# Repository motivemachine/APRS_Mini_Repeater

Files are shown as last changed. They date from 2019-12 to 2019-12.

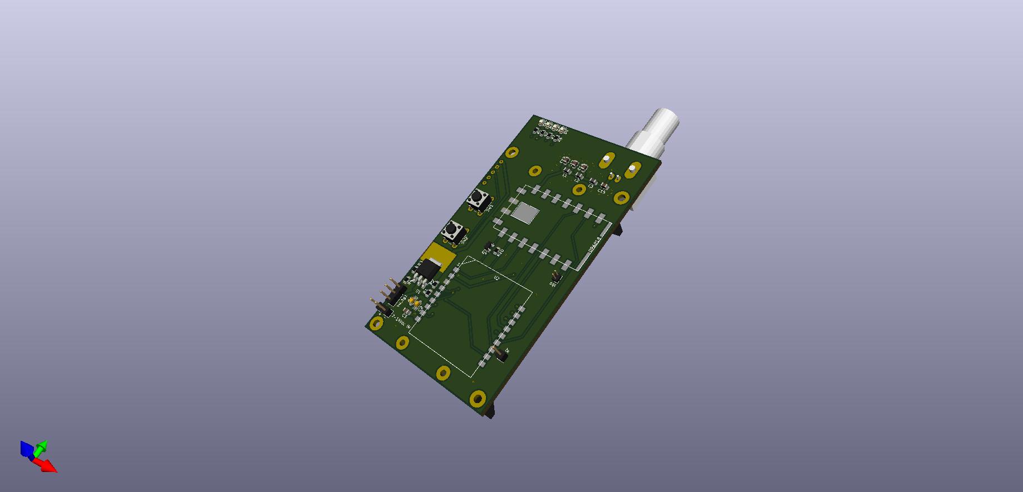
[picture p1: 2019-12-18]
APRS_MicroNode.jpg

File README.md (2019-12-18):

### Project goal
The goal of this in-progress project is to create a simple APRS position reporter and repeater. This will serve as a stepping stone toward my full APRS text-message radio, while providing a useful purpose later as an easy to deploy repeater for better coverage between groups of hikers, bikers, or road-trippers. It will be able to use smart-beaconing to know when to update it's position, and if repeater mode is turned on, repeat any packets heard that are not addressed to it.

This PCB uses the nano-modem board I developed here: [APRS Nanomodem]https://gitlab.com/motivemachine/aprs-nanomodem
Which is based on the Arduino TNC circuit and library developed by Mark Qvist here: [unsigned.io](https://unsigned.io/micromodem/)

### Project status
PCB is complete and undergoing testing. Board is designed in Kicad 5.1, gerbers will be available soon. 

 Writing the code has just started. I'll get the smart beaconing working first, then start in on the repeater functions and [hopefully] get it to conform with the APRS repeater WIDEn-N standard:
[APRS 101](http://www.aprs.org/doc/APRS101.PDF)

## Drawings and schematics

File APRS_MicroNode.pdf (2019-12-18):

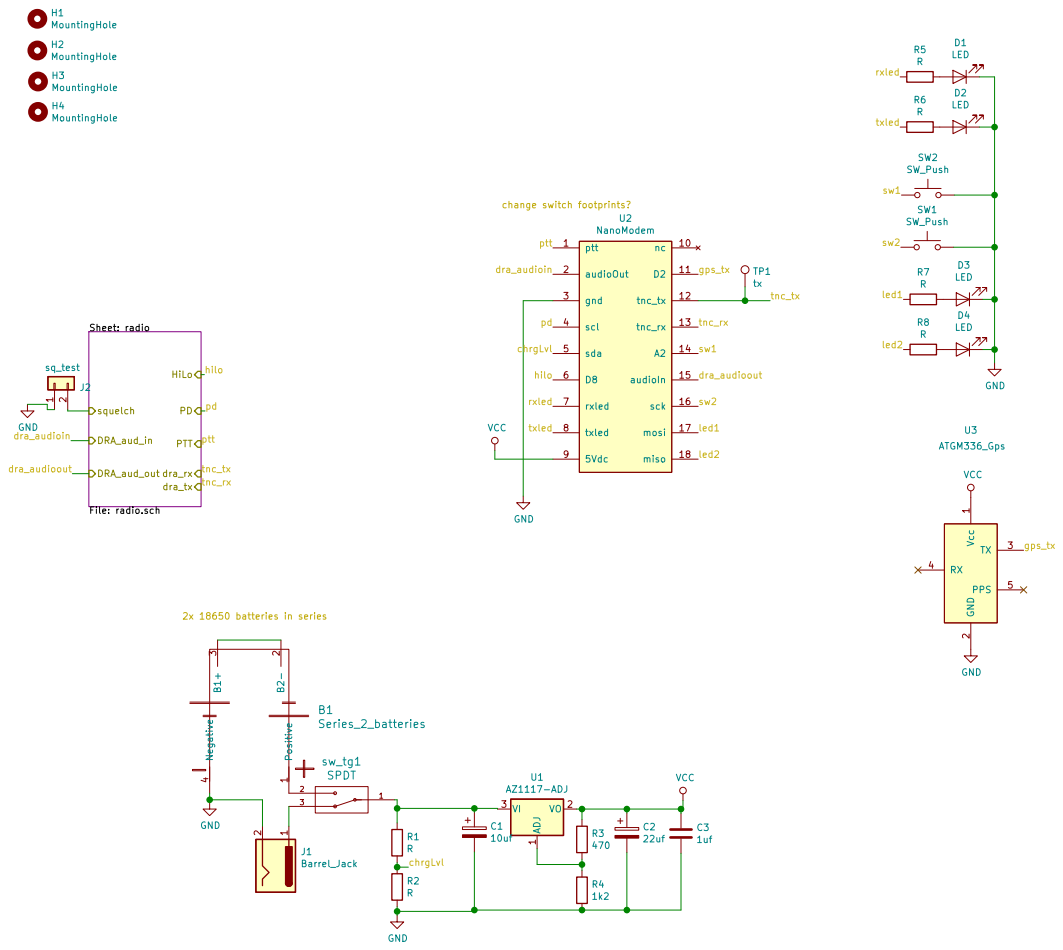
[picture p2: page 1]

2 TX 3 RX 4 PPS 5 U3 ATGM336_Gps SW2 SW_Push SW1 SW_Push GND

4 B1Series_2_batteries ADJ 1 VO 2 VI 3 U1 AZ1117-ADJ C1

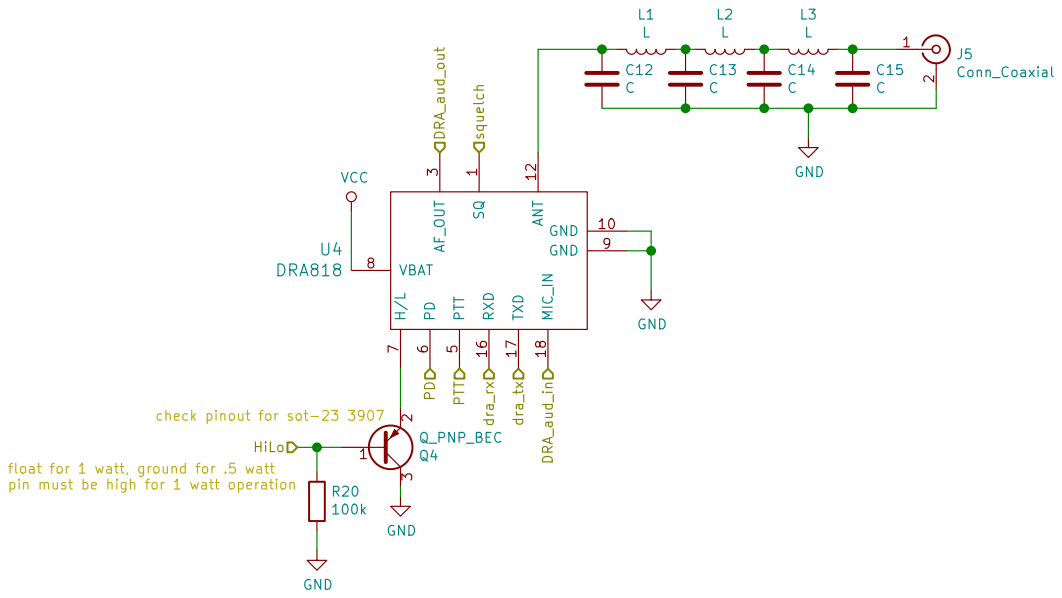
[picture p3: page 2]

1 GND ANT 10 12 RXD 16 TXD 17 MIC_IN 18 AF_OUT

check pinout for sot-23 3907

float for 1 watt, ground for .5 watt
pin must be high for 1 watt operation

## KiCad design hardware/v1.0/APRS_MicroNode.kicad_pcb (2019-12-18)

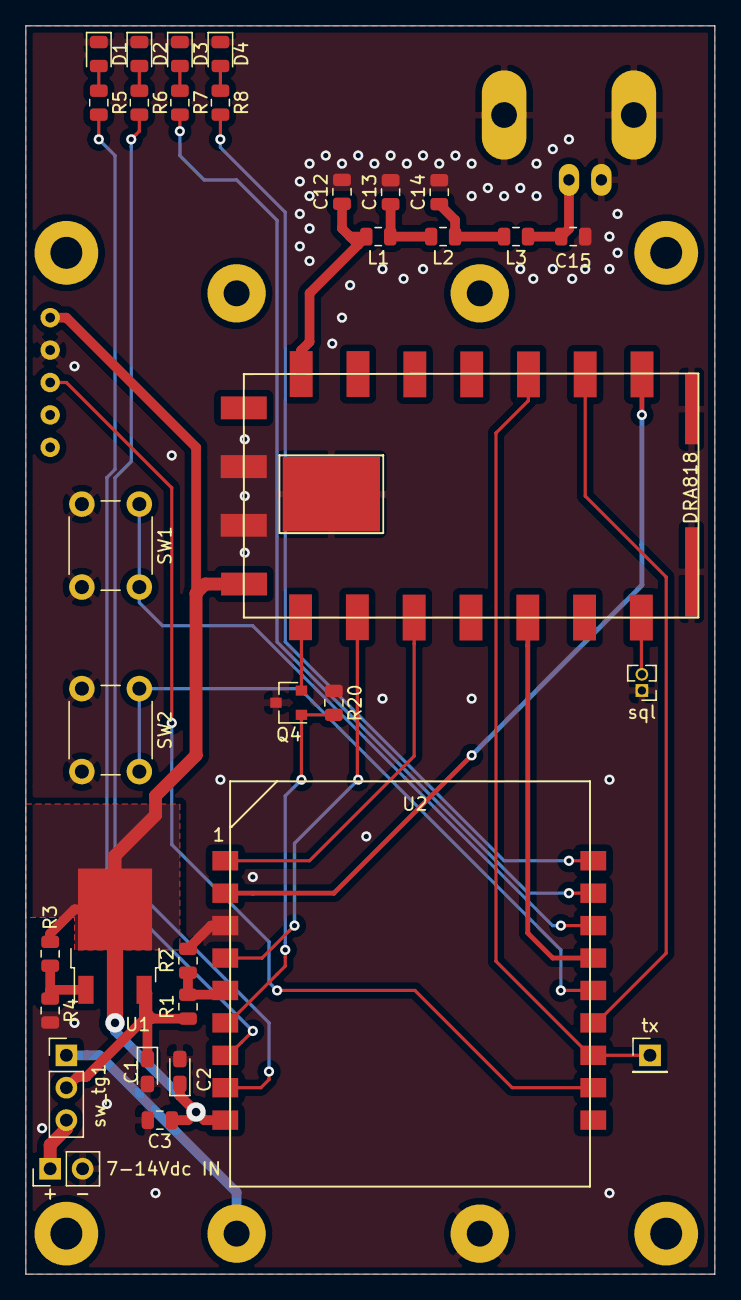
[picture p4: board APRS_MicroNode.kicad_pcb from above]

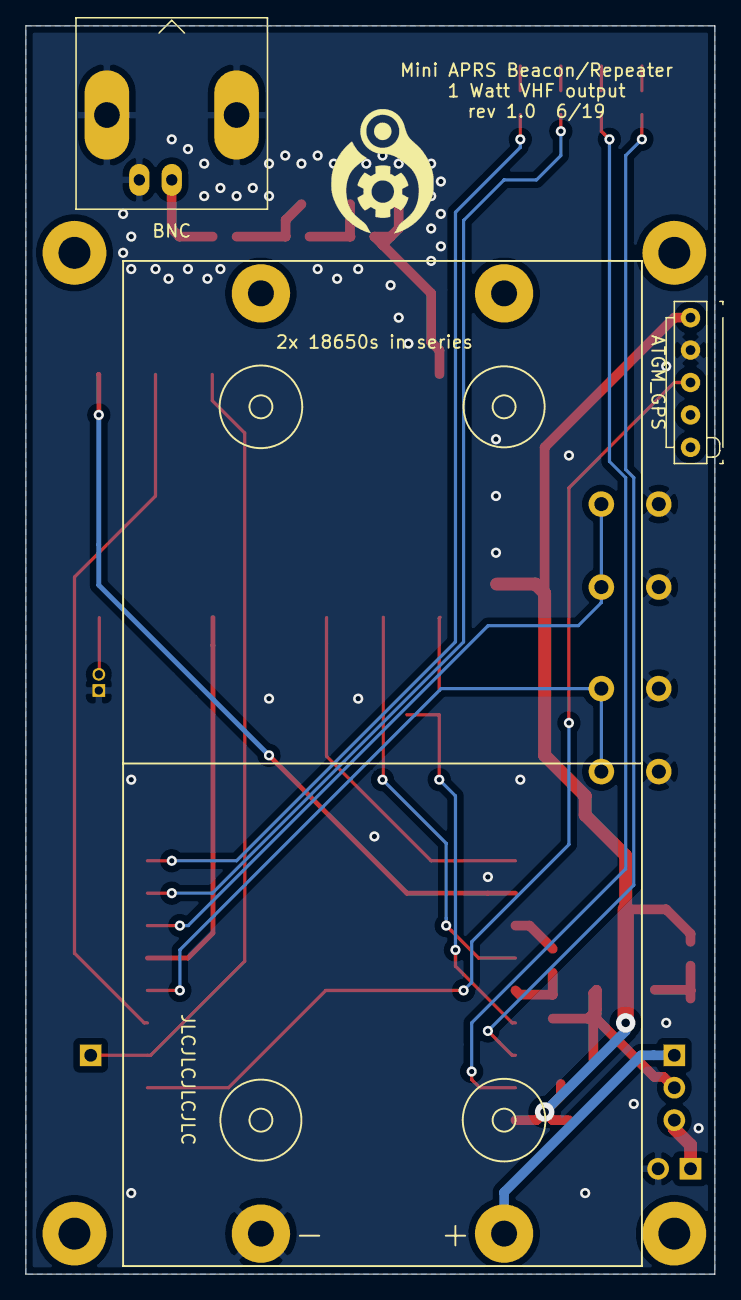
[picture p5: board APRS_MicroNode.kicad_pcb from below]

Board: 2 copper layers, 54.0 x 97.8 mm, 40 parts (3 on the bottom side), 32 nets.

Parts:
2x 18650s in series: Series_2_batteries; 18650_Double_Holder
ATGM_GPS: ATGM336_Gps; ATGM336_GPS_Vertical
BNC: Conn_Coaxial; BNC_pcbmount_h
C1: 10uf; CP_EIA-2012-12_Kemet-R_Pad1.30x1.05mm_HandSolder
C2: 22uf; CP_EIA-2012-12_Kemet-R_Pad1.30x1.05mm_HandSolder
C3: 1uf; C_0805_2012Metric
C12, C13, C14, C15: C; C_0805_2012Metric
D1, D2, D3, D4: LED; LED_0805_2012Metric
DRA818: DRA818
H1, H2, H3, H4: MountingHole; MountingHole_2.5mm_Pad
J1: Barrel_Jack; PinHeader_1x02_P2.54mm_Vertical
L1, L2, L3: L; L_0805_2012Metric
Q4: Q_PNP_BEC; SOT-23
R1, R2, R5, R6, R7, R8: R; R_0805_2012Metric
R3: 470; R_0805_2012Metric
R4: 1k2; R_0805_2012Metric
R20: 100k; R_0805_2012Metric
SW1, SW2: SW_Push; SW_PUSH_6mm_H5mm
U1: AZ1117-ADJ; TO-252-3_TabPin2
U2: NanoModem; Nanomodem_TNC_2.0
sql: sq_test; PinHeader_1x02_P1.27mm_Vertical
sw_tg1: SPDT; PinHeader_1x03_P2.54mm_Vertical
tx: tx; PinHeader_1x01_P2.54mm_Vertical

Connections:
/chrgLvl: R1.2, R2.1, U2.5
/dra_audioin: DRA818.18, U2.2
/dra_audioout: DRA818.3, U2.15
/gps_tx: ATGM_GPS.3, U2.11
/hilo: Q4.1, R20.2, U2.6
/led1: R7.2, U2.17
/led2: R8.2, U2.18
/pd: DRA818.6, U2.4
/ptt: DRA818.5, U2.1
/radio/squelch: DRA818.1, sql.2
/rxled: R5.2, U2.7
/sw1: SW2.1, U2.14
/sw2: SW1.1, U2.16
/tnc_rx: DRA818.17, U2.13
/tnc_tx: DRA818.16, U2.12, tx.1
/txled: R6.2, U2.8
GND: 2x 18650s in series.4, ATGM_GPS.2, BNC.2, C1.2, C2.2, C3.2, C12.2, C13.2, C14.2, C15.2, D1.1, D2.1, D3.1, D4.1, DRA818.9, DRA818.10, J1.2, Q4.3, R2.2, R4.2, R20.1, SW1.2, SW2.2, U2.3, sql.1
unnamed: 2x 18650s in series.1, sw_tg1.2
unnamed: 2x 18650s in series.2, 2x 18650s in series.3
unnamed: C1.1, R1.1, U1.3, sw_tg1.1
unnamed: C12.1, DRA818.12, L1.2
unnamed: C13.1, L1.1, L2.2
unnamed: C14.1, L2.1, L3.2
unnamed: BNC.1, C15.1, L3.1
unnamed: D1.2, R5.1
unnamed: D2.2, R6.1
unnamed: D3.2, R7.1
unnamed: D4.2, R8.1
unnamed: J1.1, sw_tg1.3
unnamed: DRA818.7, Q4.2
unnamed: R3.2, R4.1, U1.1
VCC: ATGM_GPS.1, C2.1, C3.1, DRA818.8, R3.1, U1.2, U2.9

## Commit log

2019-12-18 upload PCB design
    [APRS_MicroNode-B_Cu.gbr, APRS_MicroNode-B_Mask.gbr, APRS_MicroNode-B_SilkS.gbr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]
2019-12-18 upload pdf schematic
